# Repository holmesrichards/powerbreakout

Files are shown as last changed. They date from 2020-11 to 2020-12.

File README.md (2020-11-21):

# Euro/Kosmo power breakout

A little board (30 x 36 mm) for connecting Eurorack or Kosmo power distribution systems to non Euro/Kosmo module PCBs. Footprints are provided for a 2x5 shrouded pin header to connect to the bus board, and a 3 pin terminal block to connect to the module PCB. (Of course one could instead solder wires to the terminal block pads.) Footprints are also provided for electrolytic capacitors from the rails to ground, and for Schottky diodes (or fuses or 10Ω resistors or ferrite beads or whatever you prefer) between the pin header and the rails, in case these are not provided for on the module PCB. If they are, the capacitors can be omitted and there are solder jumpers that can be filled to bypass the diode pads.

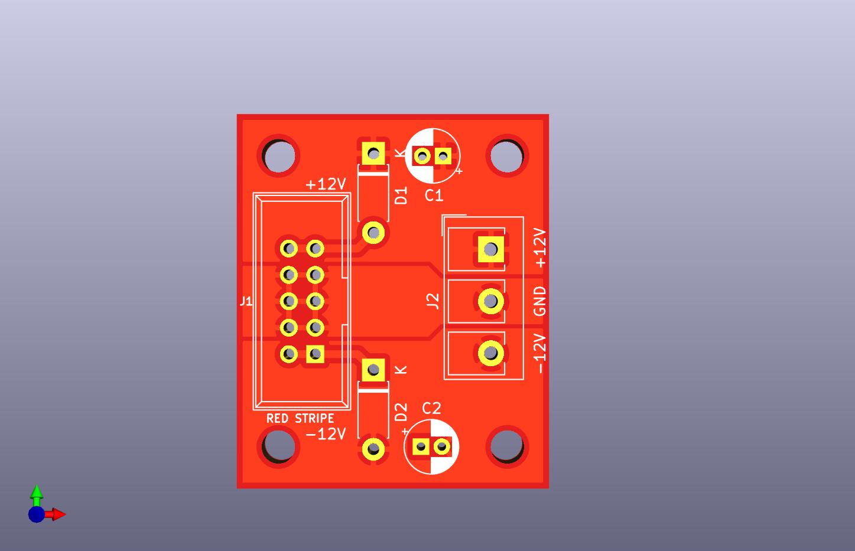
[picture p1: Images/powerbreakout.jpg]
Euro/Kosmo power breakout PCB front

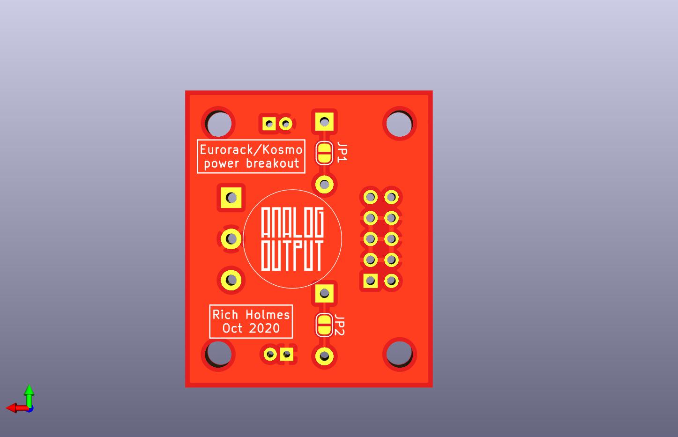
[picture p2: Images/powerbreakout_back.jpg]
Euro/Kosmo power breakout PCB back


[Schematic, such as it is](Docs/powerbreakout.pdf) 

[BOM](Docs/powerbreakout_bom.md)

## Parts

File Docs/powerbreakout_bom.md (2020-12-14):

# powerbreakout.sch BOM

Sat 21 Nov 2020 02:01:23 PM EST

Generated from schematic by Eeschema 5.1.8-db9833491\~87\~ubuntu20.04.1

**Component Count:** 8

| Value | Qty | Part | Description | Vendor |
| ----- | --- | ---- | --- | --- |
| C1, C2 | 2 | 10uF | Polarized capacitor | Tayda A-4349 |
| D1, D2 | 2 | 1N5817 | Schottky diode | Tayda A-159 |
| J1 | 1 | Synth_power_2x5 | 2x5 shrouded pin header | Tayda A-2939 |
| J2 | 1 | Screw_Terminal_01x03 | Terminal block, 5 mm spacing | Tayda A-669 |

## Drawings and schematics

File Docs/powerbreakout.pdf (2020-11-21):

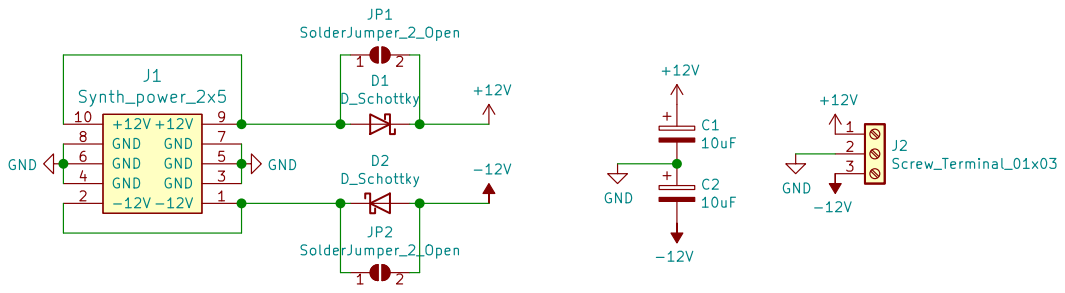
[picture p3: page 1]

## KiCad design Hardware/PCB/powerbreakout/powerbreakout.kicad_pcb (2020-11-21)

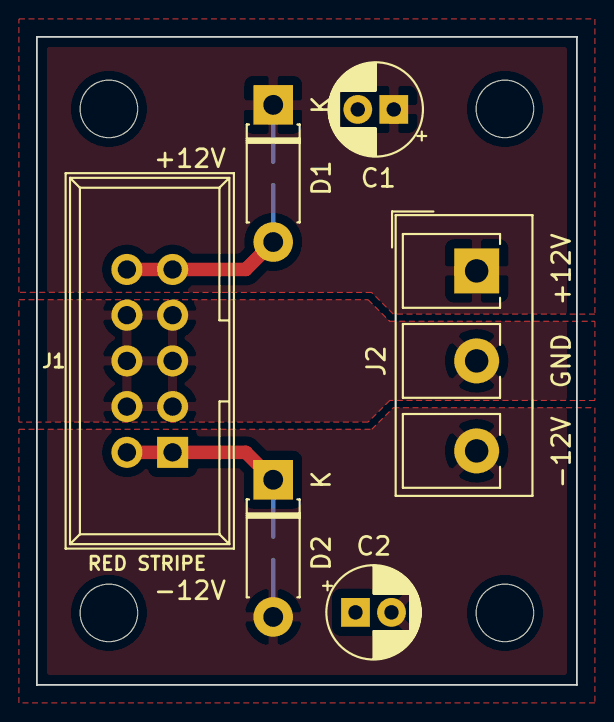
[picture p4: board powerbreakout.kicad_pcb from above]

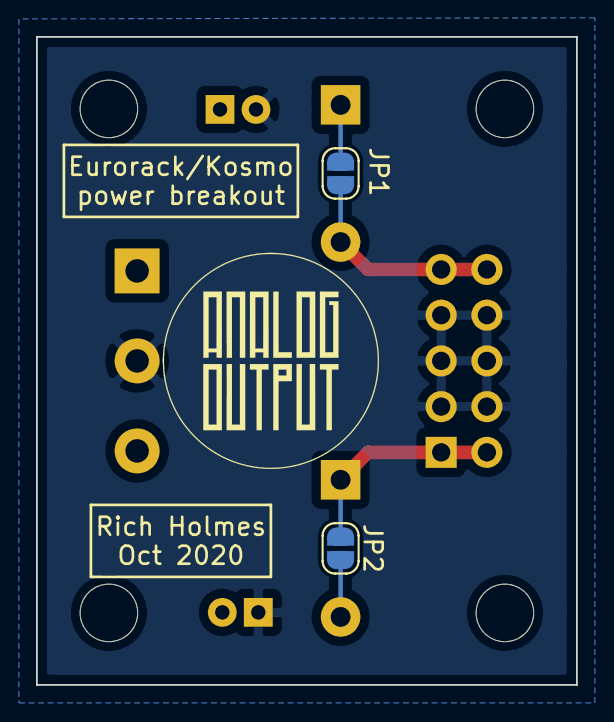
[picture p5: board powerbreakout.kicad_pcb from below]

Board: 2 copper layers, 30.0 x 36.0 mm, 8 parts (2 on the bottom side), 5 nets.

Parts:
C1, C2: 10uF; CP_Radial_D5.0mm_P2.00mm
D1, D2: D_Schottky; D_DO-41_SOD81_P7.62mm_Horizontal
J1: Synth_power_2x5; Power_Header
J2: Screw_Terminal_01x03; TerminalBlock_Degson_DG301_1x03_P5.00mm_Vertical
JP1, JP2: SolderJumper_2_Open; SolderJumper-2_P1.3mm_Open_RoundedPad1.0x1.5mm

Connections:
+12V: C1.1, D1.1, J2.1, JP1.2
-12V: C2.2, D2.2, J2.3, JP2.2
GND: C1.2, C2.1, J1.3, J1.4, J1.5, J1.6, J1.7, J1.8, J2.2
unnamed: D1.2, J1.9, J1.10, JP1.1
unnamed: D2.1, J1.1, J1.2, JP2.1

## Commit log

2020-12-01 Updated Gerbers
    [powerbreakout-B_Cu.gbr, powerbreakout-B_Mask.gbr, powerbreakout-B_Paste.gbr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]
2020-12-14 Add Tayda numbers to BOM
2020-12-14 PCB silk/fab/courtyard tweaks
2021-01-02 Footprints updated
2021-02-19 Footprint update
